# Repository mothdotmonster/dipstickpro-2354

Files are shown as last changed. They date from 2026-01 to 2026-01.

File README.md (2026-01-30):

# DIPSTICKPRO 2354
picture of the microcontroller on a grid background

pro micro sized, with all the features i wanted from other similar sized things

put python on it: https://github.com/mothdotmonster/circuitpython/releases

## pinout
pinout

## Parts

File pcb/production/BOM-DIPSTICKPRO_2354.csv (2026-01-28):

Comment | Designator | Footprint | LCSC | Quantity
100n | C11,C12,C13,C14,C15,C16,C17,C18,C8 | C_0402_1005Metric | C1525 | 9
15p | C3,C4 | C_0402_1005Metric | C1548 | 2
1k | R2,R4,R6 | R_0402_1005Metric | C11702 | 3
1u | C1 | C_0402_1005Metric | C52923 | 1
27 | R7,R8 | R_0402_1005Metric | C25092 | 2
3.3u | L1 | L_pol_2016 | C42411119 | 1
33 | R5 | R_0402_1005Metric | C25105 | 1
4.7u | C10,C6,C7,C9 | C_0402_1005Metric | C23733 | 4
5.1k | R1,R3 | R_0402_1005Metric | C25905 | 2
ABM8-272-T3 | Y1 | Crystal_SMD_3225-4Pin_3.2x2.5mm | C20625731 | 1
NCP1117-3.3_SOT223 | U2 | SOT-23-3 | C5446 | 1
RP2350_60QFN | U1 | RP2350-QFN-60-1EP_7x7_P0.4mm_EP3.4x3.4mm_ThermalVias | C41378174 | 1
SW_Push | SW1,SW2 | SW_SPST_TS-1088-xR020 | C720477 | 2
USB_C_Receptacle | J2 | USB-C_16 | C165948 | 1

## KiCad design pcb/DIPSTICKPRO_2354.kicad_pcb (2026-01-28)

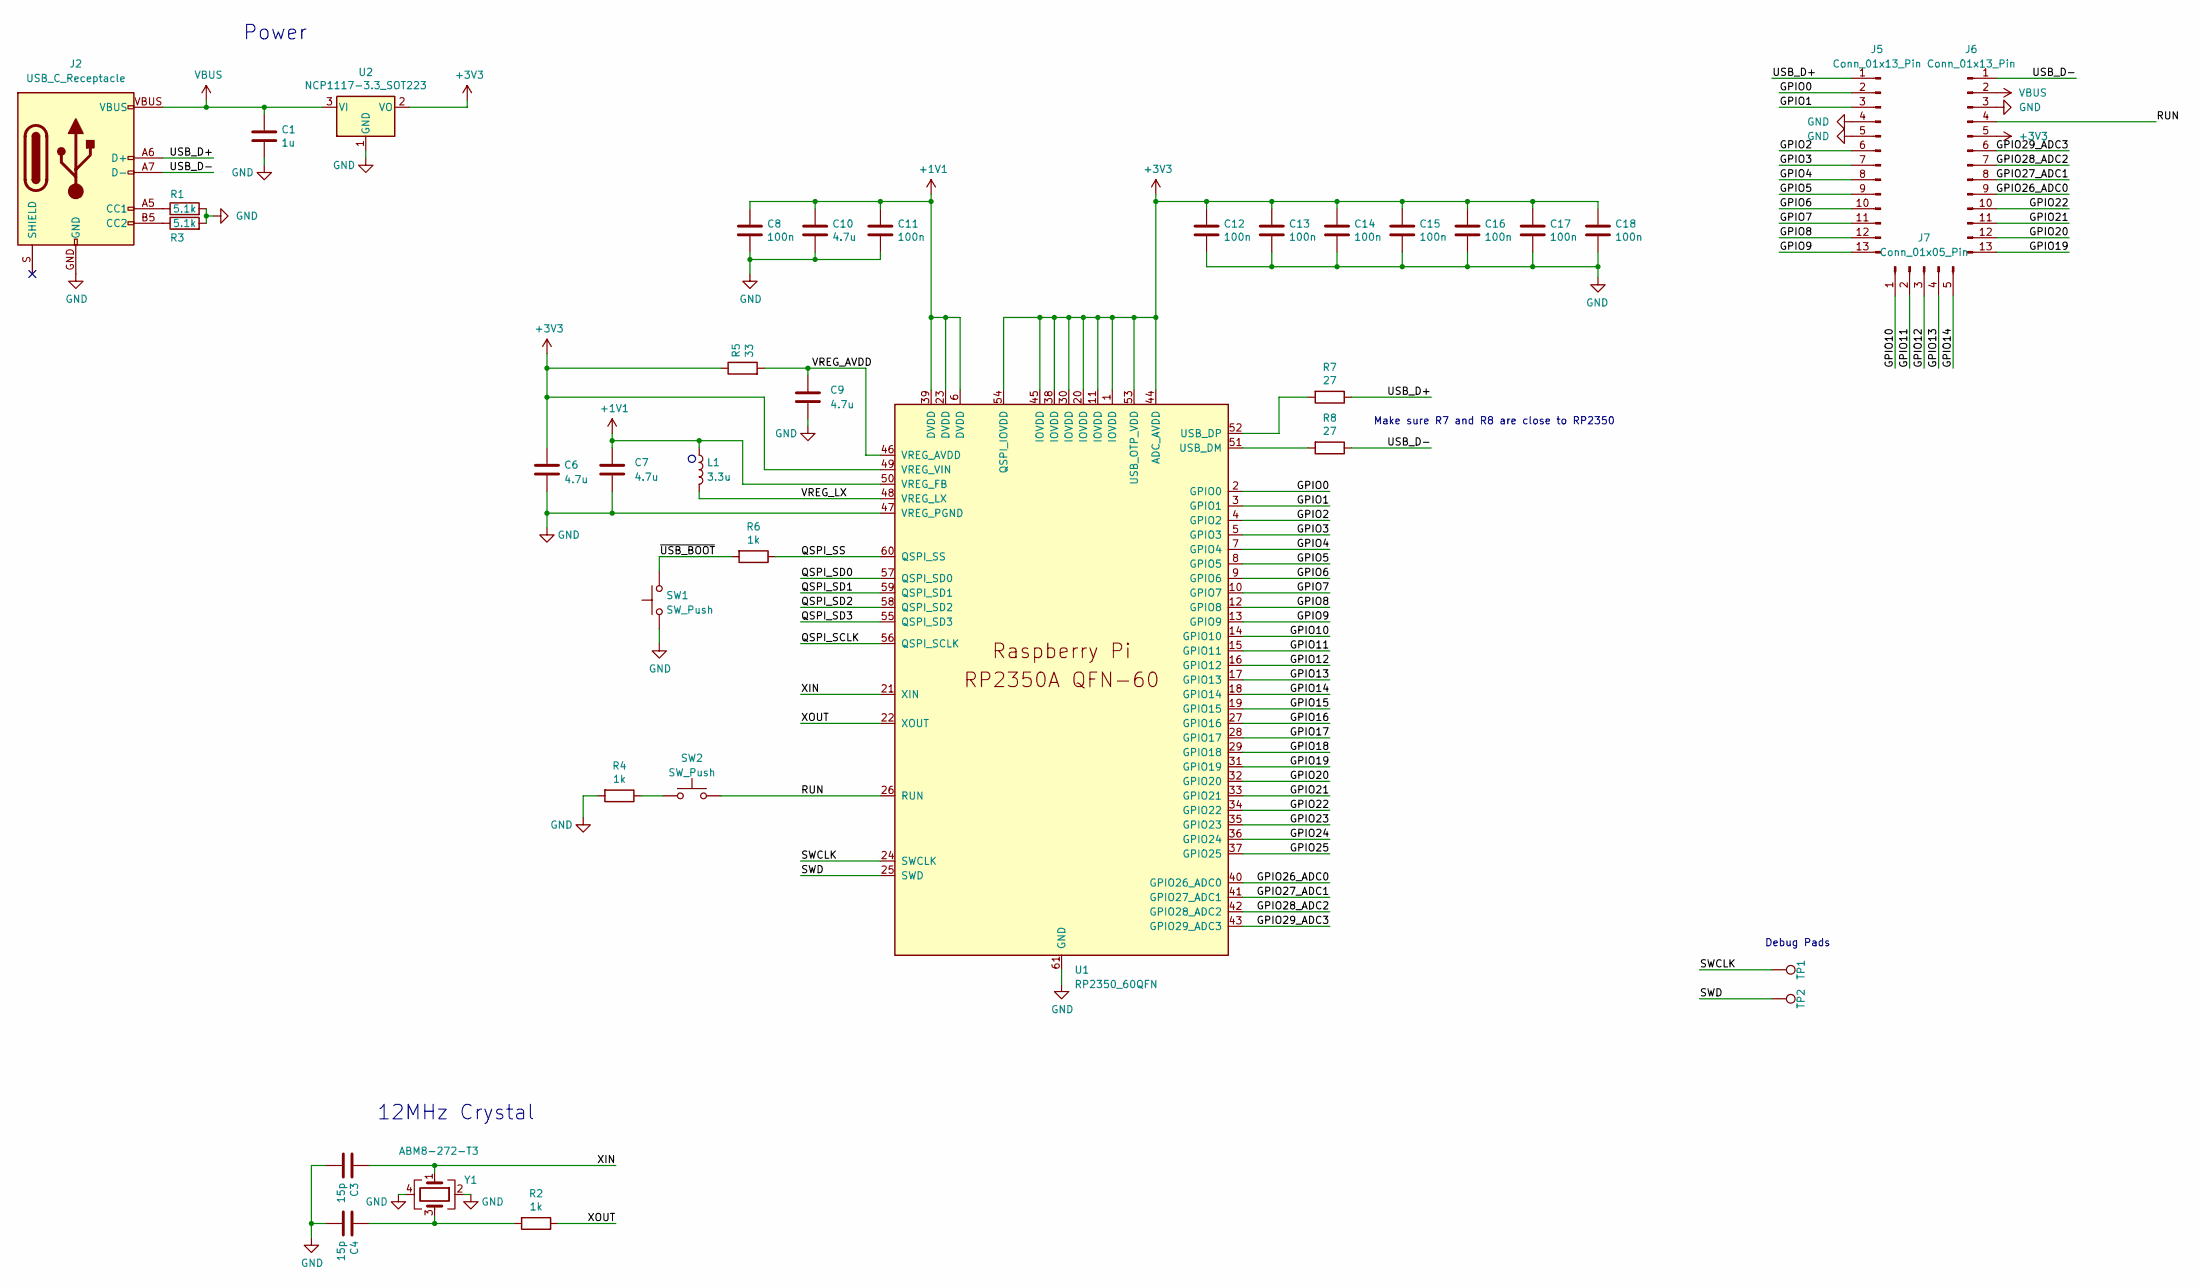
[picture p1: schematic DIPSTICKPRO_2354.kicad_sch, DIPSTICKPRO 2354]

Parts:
C1: 1u; C_0402_1005Metric
C3, C4: 15p; C_0402_1005Metric
C6, C7: 4.7u; C_0402_1005Metric_small_pads
C8, C11, C12, C13, C14, C15, C16, C17, C18: 100n; C_0402_1005Metric
C9, C10: 4.7u; C_0402_1005Metric
J2: USB_C_Receptacle; USB-C_16
J5, J6: Conn_01x13_Pin; 1x12_P2.54mm_Castellated
J7: Conn_01x05_Pin; 1x05_P2.54mm_Castellated
L1: 3.3u; L_pol_2016
R1, R3: 5.1k; R_0402_1005Metric; LCSC C25905
R2, R4, R6: 1k; R_0402_1005Metric
R5: 33; R_0402_1005Metric
R7, R8: 27; R_0402_1005Metric
SW1, SW2: SW_Push; SW_SPST_TS-1088-xR020
TP1, TP2: 0.5mm; TestPoint-0.5mm
U1: RP2350_60QFN; RP2350-QFN-60-1EP_7x7_P0.4mm_EP3.4x3.4mm_ThermalVias
U2: NCP1117-3.3_SOT223; SOT-23-3; JLC C5446
Y1: ABM8-272-T3; Crystal_SMD_3225-4Pin_3.2x2.5mm

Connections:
+1V1: C7.1, C8.1, C10.1, C11.1, L1.1, U1.6 (DVDD), U1.23 (DVDD), U1.39 (DVDD), U1.50 (VREG_FB)
+3V3: C6.1, C12.1, C13.1, C14.1, C15.1, C16.1, C17.1, C18.1, J6.5, R5.1, U1.1 (IOVDD), U1.11 (IOVDD), U1.20 (IOVDD), U1.30 (IOVDD), U1.38 (IOVDD), U1.44 (ADC_AVDD), U1.45 (IOVDD), U1.49 (VREG_VIN), U1.53 (USB_OTP_VDD), U1.54 (QSPI_IOVDD), U2.2 (VO)
/GPIO0: J5.2, U1.2 (GPIO0)
/GPIO1: J5.3, U1.3 (GPIO1)
/GPIO2: J5.6, U1.4 (GPIO2)
/GPIO3: J5.7, U1.5 (GPIO3)
/GPIO4: J5.8, U1.7 (GPIO4)
/GPIO5: J5.9, U1.8 (GPIO5)
/GPIO6: J5.10, U1.9 (GPIO6)
/GPIO7: J5.11, U1.10 (GPIO7)
/GPIO8: J5.12, U1.12 (GPIO8)
/GPIO9: J5.13, U1.13 (GPIO9)
/GPIO10: J7.1, U1.14 (GPIO10)
/GPIO11: J7.2, U1.15 (GPIO11)
/GPIO12: J7.3, U1.16 (GPIO12)
/GPIO13: J7.4, U1.17 (GPIO13)
/GPIO14: J7.5, U1.18 (GPIO14)
/GPIO15: U1.19 (GPIO15)
/GPIO16: U1.27 (GPIO16)
/GPIO17: U1.28 (GPIO17)
/GPIO18: U1.29 (GPIO18)
/GPIO19: J6.13, U1.31 (GPIO19)
/GPIO20: J6.12, U1.32 (GPIO20)
/GPIO21: J6.11, U1.33 (GPIO21)
/GPIO22: J6.10, U1.34 (GPIO22)
/GPIO23: U1.35 (GPIO23)
/GPIO24: U1.36 (GPIO24)
/GPIO25: U1.37 (GPIO25)
/GPIO26_ADC0: J6.9, U1.40 (GPIO26_ADC0)
/GPIO27_ADC1: J6.8, U1.41 (GPIO27_ADC1)
/GPIO28_ADC2: J6.7, U1.42 (GPIO28_ADC2)
/GPIO29_ADC3: J6.6, U1.43 (GPIO29_ADC3)
/QSPI_SCLK: U1.56 (QSPI_SCLK)
/QSPI_SD0: U1.57 (QSPI_SD0)
/QSPI_SD1: U1.59 (QSPI_SD1)
/QSPI_SD2: U1.58 (QSPI_SD2)
/QSPI_SD3: U1.55 (QSPI_SD3)
/QSPI_SS: R6.1, U1.60 (QSPI_SS)
/RUN: J6.4, SW2.2, U1.26 (RUN)
/SWCLK: TP1.1, U1.24 (SWCLK)
/SWD: TP2.1, U1.25 (SWD)
/USB_D+: J2.A6 (D+), J2.B6 (D+), J5.1, R7.1
/USB_D-: J2.A7 (D-), J2.B7 (D-), J6.1, R8.1
/VREG_AVDD: C9.1, R5.2, U1.46 (VREG_AVDD)
/VREG_LX: L1.2, U1.48 (VREG_LX)
/XIN: C3.1, U1.21 (XIN), Y1.1
/XOUT: R2.1, U1.22 (XOUT)
/~USB_BOOT: R6.2, SW1.2
GND: C1.2, C3.2, C4.2, C6.2, C7.2, C8.2, C9.2, C10.2, C11.2, C12.2, C13.2, C14.2, C15.2, C16.2, C17.2, C18.2, J2.GND, J5.4, J5.5, J6.3, R1.2, R3.2, R4.2, SW1.1, U1.47 (VREG_PGND), U1.61 (GND), U2.1 (GND), Y1.2, Y1.4
unnamed: C4.1, R2.2, Y1.3
unnamed: J2.A5 (CC1), R1.1
unnamed: J2.B5 (CC2), R3.1
unnamed: R4.1, SW2.1
unnamed: R8.2, U1.51 (USB_DM)
unnamed: R7.2, U1.52 (USB_DP)
VBUS: C1.1, J2.VBUS, J6.2, U2.3 (VI)

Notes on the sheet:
Debug Pads
Make sure R7 and R8 are close to RP2350
12MHz Crystal
Power

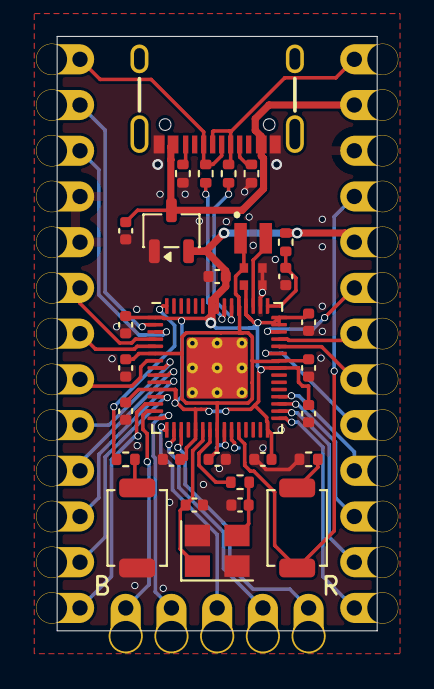
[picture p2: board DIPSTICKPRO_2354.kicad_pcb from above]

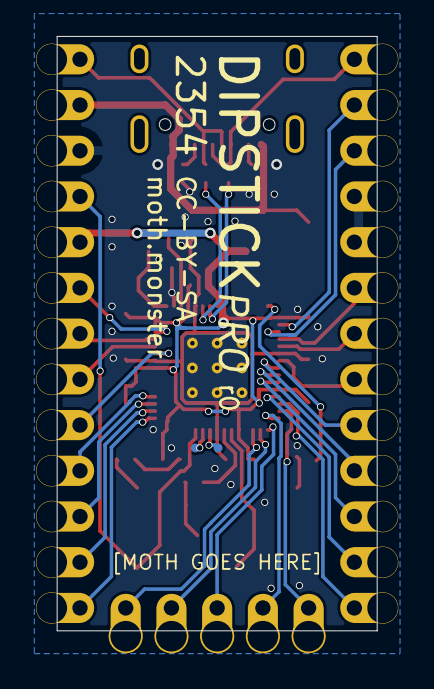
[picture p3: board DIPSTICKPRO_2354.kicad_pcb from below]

Board: 2 copper layers, 17.8 x 33.0 mm, 36 parts (4 on the bottom side), 44 nets.

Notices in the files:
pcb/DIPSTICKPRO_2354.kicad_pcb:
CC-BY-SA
